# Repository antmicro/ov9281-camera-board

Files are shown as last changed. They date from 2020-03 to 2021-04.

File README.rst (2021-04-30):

========================
OV9281 Dual camera board
========================

Copyright (c) 2019-2021 `Antmicro <https://www.antmicro.com>`_

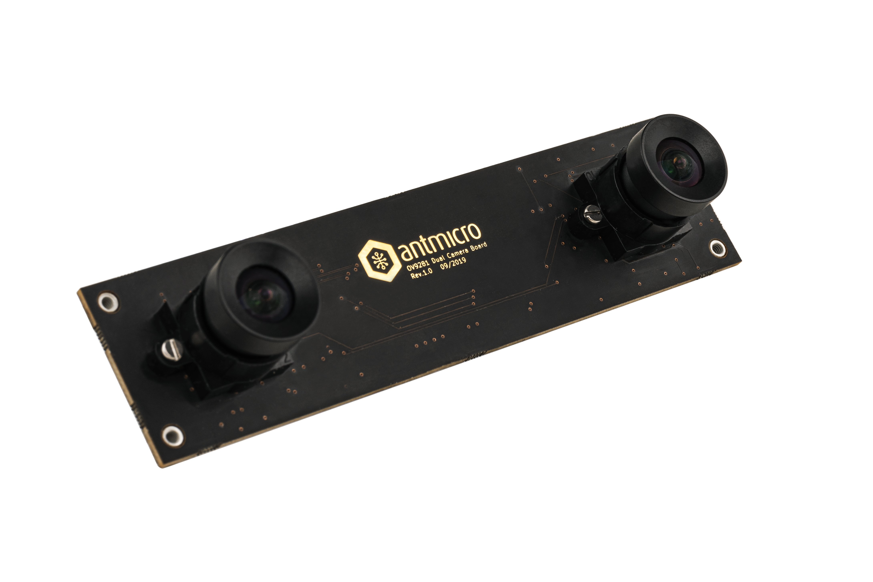
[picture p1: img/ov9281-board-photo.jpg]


Overview
========

This repository contains open hardware design files for a dual camera module created by `Antmicro <https://antmicro.com/>`_.
This board is equipped with a pair of 1-megapixel `OmniVision OV9281 <https://www.ovt.com/sensors/OV9281>`_ image sensors with mounting holes for standard S-Mount (M12) lens holders.
Each sensor can be connected to a host platform via a separate 2-lane MIPI CSI-2 interface.
The PCB design files have been written in KiCad and released as Open Source Hardware (OSHW).

Key Features
============

+------------------------------+--------------------------------------+
| Image sensor(s):             | 2 x monochrome global shutter OV9281 |
+------------------------------+--------------------------------------+
| Pixel size:                  | 3μm x 3 μm                           |
+------------------------------+--------------------------------------+
| Active array size:           | 1280 x 800                           |
+------------------------------+--------------------------------------+
| Optical size:                | 1/4 inch                             |
+------------------------------+--------------------------------------+
| Lens mount:                  | M-12 (S-Mount)                       |
+------------------------------+--------------------------------------+
| Output interface:            | 50-pin FFC connector                 |
+------------------------------+--------------------------------------+
| Output formats:              | 8/10-bit BW RAW                      |
+------------------------------+--------------------------------------+
| Maximum image transfer rate: | 1280 x 800 @60 fps                   |
+------------------------------+--------------------------------------+

Interface connector
===================

The board uses a 50-pin FFC connector which exposes two separate MIPI CSI interfaces for both cameras, along with power supply rails and separate I2C buses used for sensor configuration.
The board is electrically compatible with Antmicro's products and open hardware designs, including `Jetson Nano baseboard <https://github.com/antmicro/jetson-nano-baseboard>`_,
`Google Coral Baseboard <https://github.com/antmicro/google-coral-baseboard>`_ or `Zynq Video Board <https://github.com/antmicro/zynq-video-board>`_.

For more details regarding the on-board circuitry please refer to the respective schematic sheets.

Mechanics
=========

Board dimensions:

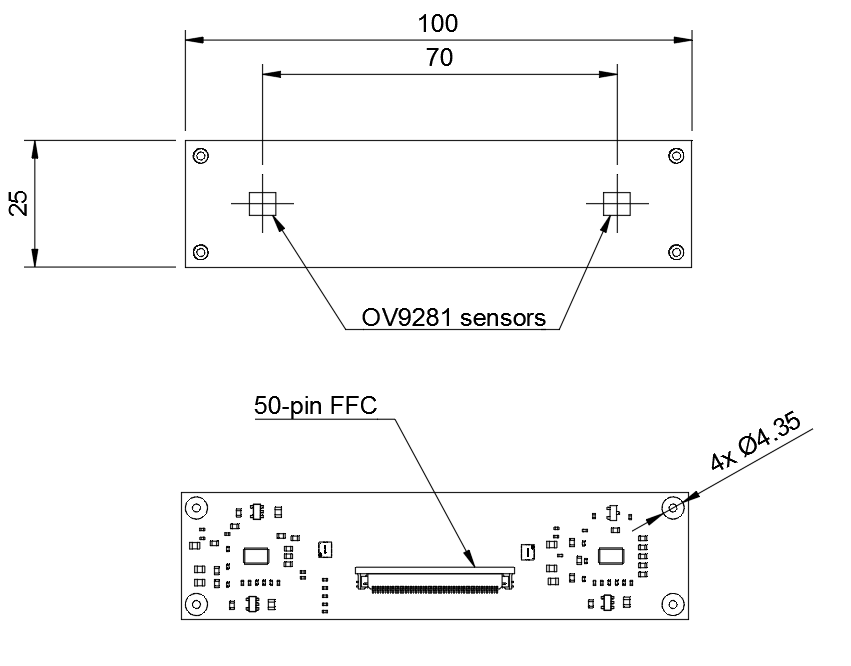
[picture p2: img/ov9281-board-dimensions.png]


License
=======

`Apache-2.0 <LICENSE>`_

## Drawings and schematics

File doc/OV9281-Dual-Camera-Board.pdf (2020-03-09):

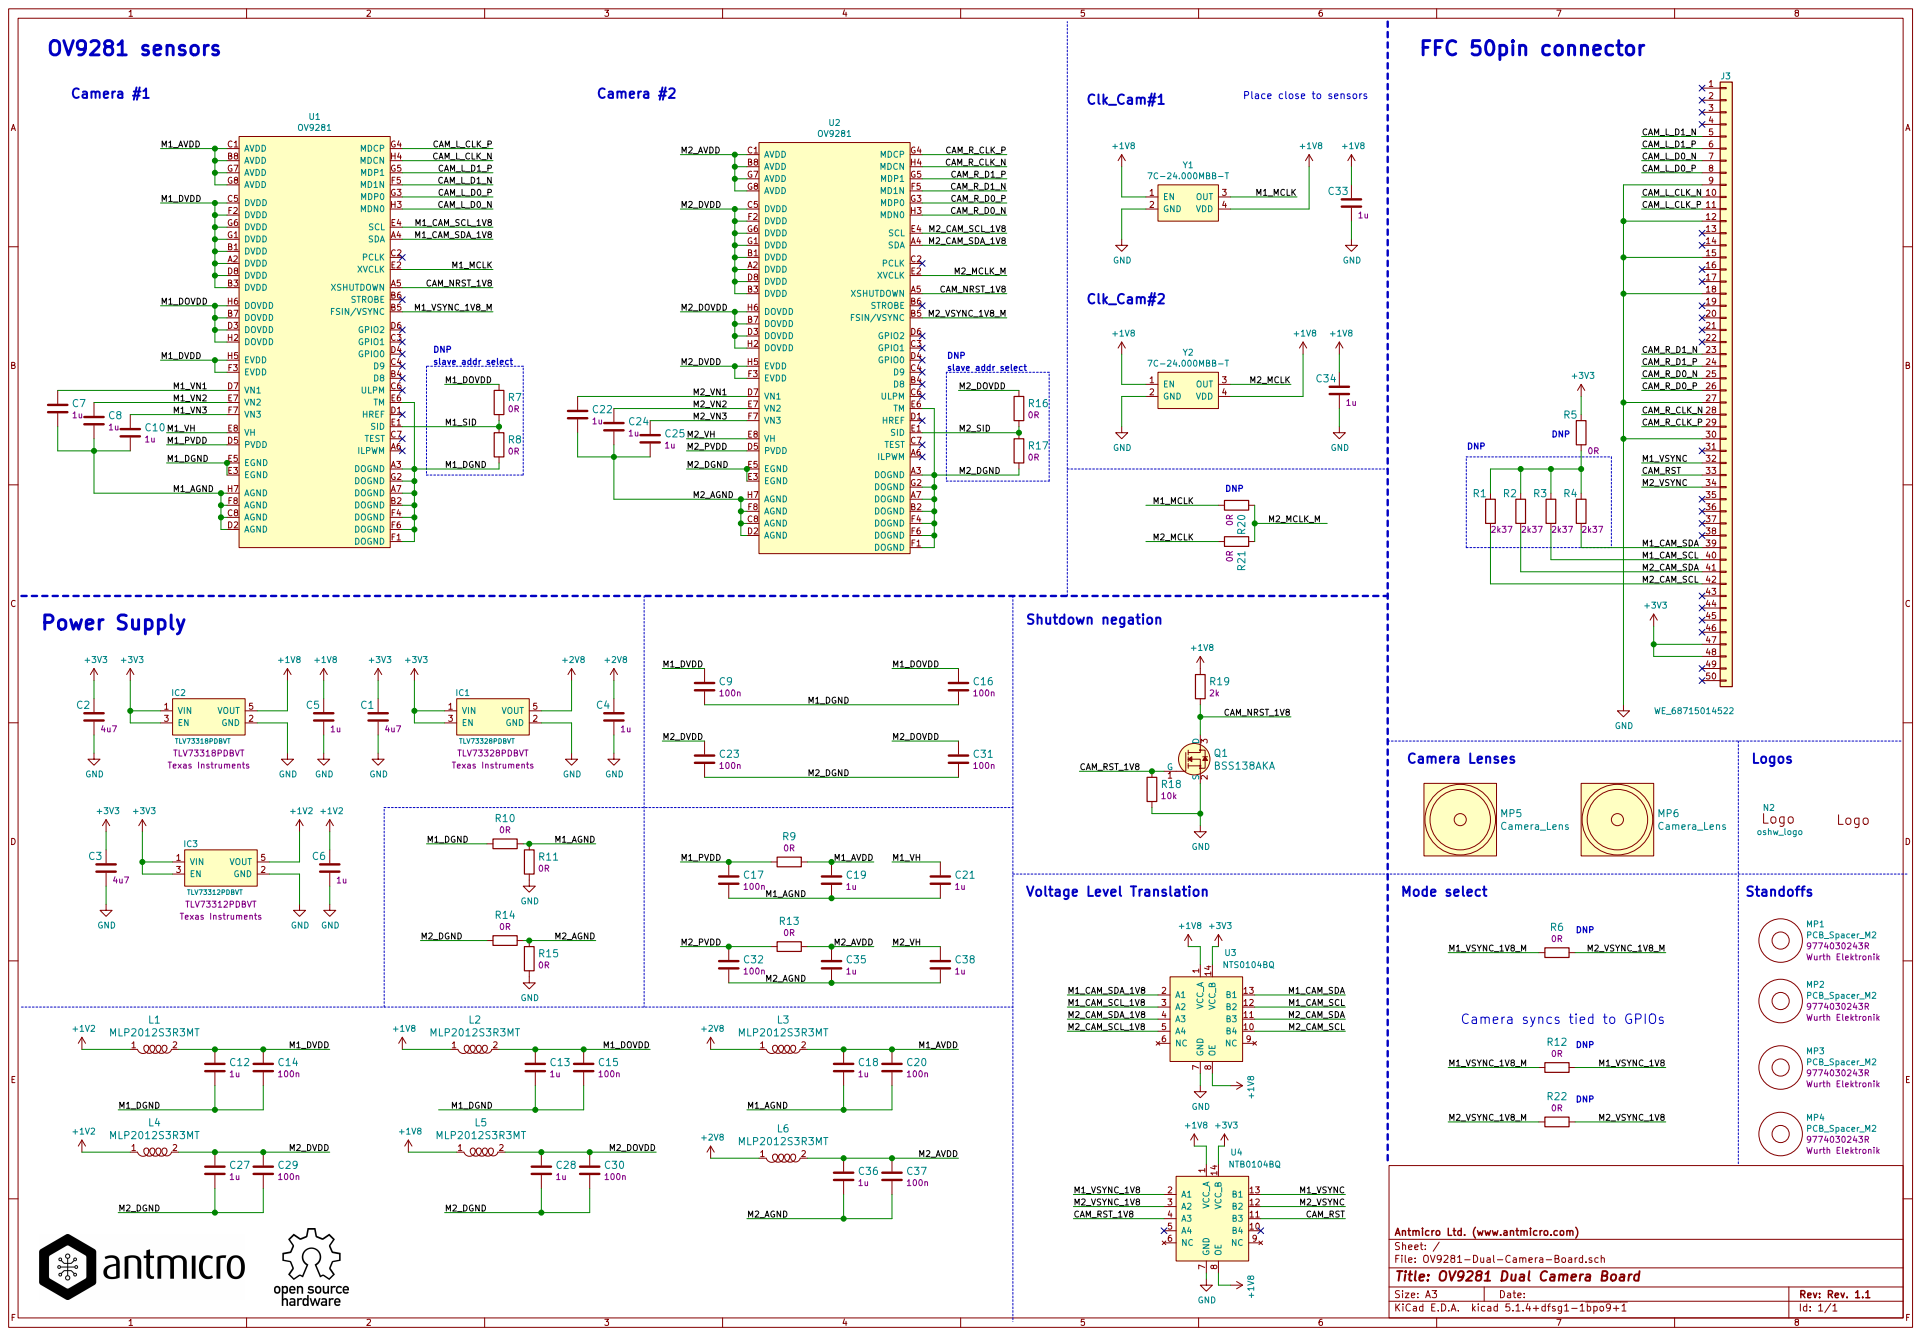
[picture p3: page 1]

File: OV9281-Dual-Camera-Board.sch Sheet: / Antmicro Ltd. (www.antmicro.com) R9

Camera syncs tied to GPIOs

Id: 1/1 Title: OV9281 Dual Camera Board

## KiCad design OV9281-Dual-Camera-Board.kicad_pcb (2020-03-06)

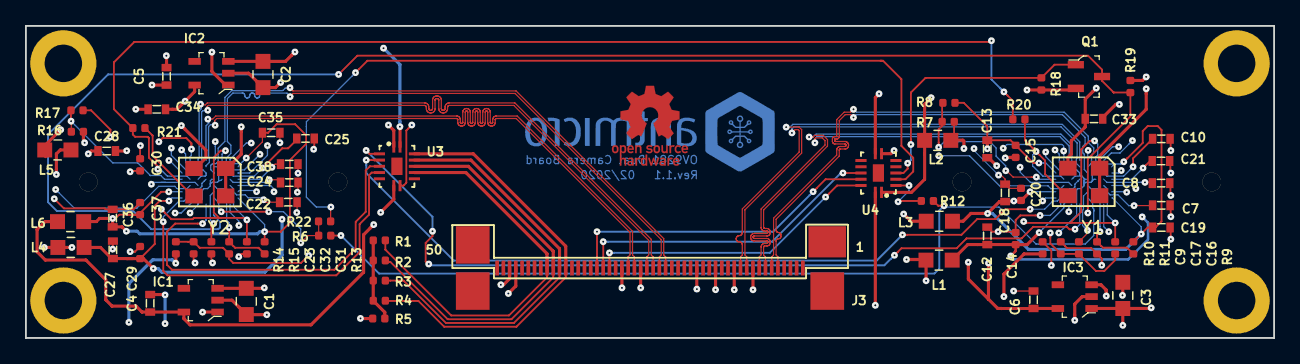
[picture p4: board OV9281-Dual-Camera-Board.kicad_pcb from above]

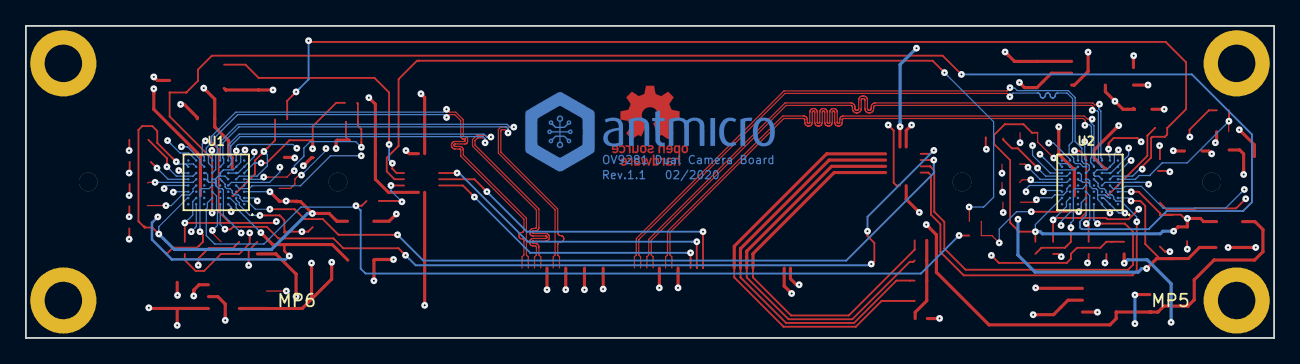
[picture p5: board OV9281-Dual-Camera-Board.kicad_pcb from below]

Board: 4 copper layers, 100.0 x 25.0 mm, 83 parts (5 on the bottom side), 60 nets.

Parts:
C1, C2, C3: C_4u7_0805; 0805-cap
C4, C5, C6, C7, C8, C10, C12, C13, C18, C19, C21, C22, C24, C25, C27, C28, C33, C34, C35, C36, C38: C_1u_0603; 0603-cap
C9, C14, C15, C16, C17, C20, C23, C29, C30, C31, C32, C37: C_100n_0402_6V3; 0402-cap
IC1: TLV73328PDBVT; SOT-23-5
IC2: TLV73318PDBVT; SOT-23-5
IC3: TLV73312PDBVT; SOT-23-5
J3: WE_68715014522
L1, L2, L3, L4, L5, L6: MLP2012S3R3MT; 0805-res
MP1, MP2, MP3, MP4: PCB_Spacer_M2; 9774030243R
MP5, MP6: Camera_Lens; Camera_Lens_20mm
N1: antmicro_logo; antmicro-logo_scaled_20mm
N2: oshw_logo; oshw-logo
Q1: BSS138AKA; SOT-23-3
R1, R2, R3, R4: R_2k37_0402; 0402-res
R5, R6, R7, R8, R9, R10, R11, R12, R13, R14, R15, R16, R17, R20, R21, R22: R_0R_0402; 0402-res
R18: R_10k_0402; 0402-res
R19: R_2k_0402; 0402-res
U1, U2: OV9281; ov9281
U3: NTS0104BQ; QDHVQFN14
U4: NTB0104BQ; QDHVQFN14
Y1, Y2: Farnell_1842027; 7C-24.000MBB-T

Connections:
+1V2: C6.1, IC3.5, L1.1, L4.1
+1V8: C5.1, C33.1, C34.1, IC2.5, L2.1, L5.1, R19.1, U3.1, U3.8, U4.1, U4.8, Y1.1, Y1.4, Y2.1, Y2.4
+2V8: C4.1, IC1.5, L3.1, L6.1
+3V3: C1.1, C2.1, C3.1, IC1.1, IC1.3, IC2.1, IC2.3, IC3.1, IC3.3, J3.47, J3.48, R5.1, U3.14, U4.14
/CAM_L_CLK_N: J3.10, U1.H4
/CAM_L_CLK_P: J3.11, U1.G4
/CAM_L_D0_N: J3.7, U1.H3
/CAM_L_D0_P: J3.8, U1.G3
/CAM_L_D1_N: J3.5, U1.F5
/CAM_L_D1_P: J3.6, U1.G5
/CAM_NRST_1V8: Q1.3, R19.2, U1.A5, U2.A5
/CAM_RST: J3.33, U4.11
/CAM_RST_1V8: Q1.1, R18.1, U4.4
/CAM_R_CLK_N: J3.28, U2.H4
/CAM_R_CLK_P: J3.29, U2.G4
/CAM_R_D0_N: J3.25, U2.H3
/CAM_R_D0_P: J3.26, U2.G3
/CAM_R_D1_N: J3.23, U2.F5
/CAM_R_D1_P: J3.24, U2.G5
/M1_AGND: C7.2, C8.2, C10.2, C17.2, C18.2, C19.2, C20.2, C21.2, R10.2, R11.1, U1.C8, U1.D2, U1.F8, U1.H7
/M1_AVDD: C18.1, C19.1, C20.1, L3.2, R9.2, U1.B8, U1.C1, U1.G7, U1.G8
/M1_CAM_SCL: J3.40, R3.2, U3.12
/M1_CAM_SCL_1V8: U1.E4, U3.3
/M1_CAM_SDA: J3.39, R4.2, U3.13
/M1_CAM_SDA_1V8: U1.A4, U3.2
/M1_DGND: C9.2, C12.2, C13.2, C14.2, C15.2, C16.2, R8.2, R10.1, U1.A3, U1.A7, U1.B2, U1.E3, U1.E5, U1.E6, U1.F1, U1.F4, U1.F6, U1.G2
/M1_DOVDD: C13.1, C15.1, C16.1, L2.2, R7.1, U1.B7, U1.D3, U1.H2, U1.H6
/M1_DVDD: C9.1, C12.1, C14.1, L1.2, U1.A2, U1.B1, U1.B3, U1.C5, U1.D8, U1.F2, U1.F3, U1.G1, U1.G6, U1.H5
/M1_MCLK: R20.2, U1.E2, Y1.3
/M1_PVDD: C17.1, R9.1, U1.D5
/M1_SID: R7.2, R8.1, U1.E1
/M1_VH: C21.1, U1.E8
/M1_VN1: C7.1, U1.D7
/M1_VN2: C8.1, U1.E7
/M1_VN3: C10.1, U1.F7
/M1_VSYNC: J3.32, U4.13
/M1_VSYNC_1V8: R12.2, U4.2
/M1_VSYNC_1V8_M: R6.1, R12.1, U1.B5
/M2_AGND: C22.2, C24.2, C25.2, C32.2, C35.2, C36.2, C37.2, C38.2, R14.2, R15.1, U2.C8, U2.D2, U2.F8, U2.H7
/M2_AVDD: C35.1, C36.1, C37.1, L6.2, R13.2, U2.B8, U2.C1, U2.G7, U2.G8
/M2_CAM_SCL: J3.42, R1.2, U3.10
/M2_CAM_SCL_1V8: U2.E4, U3.5
/M2_CAM_SDA: J3.41, R2.2, U3.11
/M2_CAM_SDA_1V8: U2.A4, U3.4
/M2_DGND: C23.2, C27.2, C28.2, C29.2, C30.2, C31.2, R14.1, R17.2, U2.A3, U2.A7, U2.B2, U2.E3, U2.E5, U2.E6, U2.F1, U2.F4, U2.F6, U2.G2
/M2_DOVDD: C28.1, C30.1, C31.1, L5.2, R16.1, U2.B7, U2.D3, U2.H2, U2.H6
/M2_DVDD: C23.1, C27.1, C29.1, L4.2, U2.A2, U2.B1, U2.B3, U2.C5, U2.D8, U2.F2, U2.F3, U2.G1, U2.G6, U2.H5
/M2_MCLK: R21.2, Y2.3
/M2_MCLK_M: R20.1, R21.1, U2.E2
/M2_PVDD: C32.1, R13.1, U2.D5
/M2_SID: R16.2, R17.1, U2.E1
/M2_VH: C38.1, U2.E8
/M2_VN1: C22.1, U2.D7
/M2_VN2: C24.1, U2.E7
/M2_VN3: C25.1, U2.F7
/M2_VSYNC: J3.34, U4.12
/M2_VSYNC_1V8: R22.2, U4.3
/M2_VSYNC_1V8_M: R6.2, R22.1, U2.B5
GND: C1.2, C2.2, C3.2, C4.2, C5.2, C6.2, C33.2, C34.2, IC1.2, IC2.2, IC3.2, J3.9, J3.12, J3.15, J3.18, J3.27, J3.30, Q1.2, R11.2, R15.2, R18.2, U3.7, U4.7, Y1.2, Y2.2
unnamed: R1.1, R2.1, R3.1, R4.1, R5.2

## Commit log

2020-03-06 Unified power rails, added power supply filters
    [OV9281.sch]
2020-03-06 Added voltage level translation
    [OV9281.sch]
2020-03-06 Updated transistor and inductors from libraries
    [OV9281.sch]
2020-03-06 Edited design rules to make bigger clearance
    [OV9281-B.Cu.gbr, OV9281-B.Fab.gbr, OV9281-B.Mask.gbr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]
2020-03-06 Defined initial component placement
    [OV9281.kicad_pcb, _saved_OV9281.sch]
2020-03-06 PCB routing
    [OV9281-B.Cu.gbr, OV9281-B.Fab.gbr, OV9281-B.Mask.gbr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]
2020-03-06 PCB ready for manufacturing
    [OV9281-B.Cu.gbr, OV9281-B.Fab.gbr, OV9281-B.Mask.gbr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]
2020-03-06 Added mounting holes for lenses
    [OV9281-B.Cu.gbr, OV9281-B.Fab.gbr, OV9281-B.Mask.gbr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]
2020-03-06 Started rev.1.1, added resistors for choosing VSYNC connection
    [OV9281-B.Adhes.gbr, OV9281-B.CrtYd.gbr, OV9281-B.Cu.gbr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]
2020-03-06 Moved some low speed signal tracks
    [OV9281-B.Fab.gbr, OV9281-Dual-Camera-Board-Rev.1.1-B.Adhes.gbr, OV9281-Dual-Camera-Board-Rev.1.1-B.CrtYd.gbr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]
2020-03-06 Minor changes
    [OV9281-Dual-Camera-Board-Rev.1.1.kicad_pcb]
2020-03-06 Pick and Place merged into a single file
    [OV9281-Dual-Camera-Board-Rev.1.1-pnp-bottom.csv, OV9281-Dual-Camera-Board-Rev.1.1-pnp.csv]
2020-03-06 Updated file structure
    [OV9281-B.Cu.gbr, OV9281-B.Fab.gbr, OV9281-B.Mask.gbr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]
2020-03-06 Unified file names and references
    [OV9281-Dual-Camera-Board-B_Adhes.gbr, OV9281-Dual-Camera-Board-B_CrtYd.gbr, OV9281-Dual-Camera-Board-B_Cu.gbr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]
2020-03-06 Added OSHW logo, updated hole spacing for lens mount
    [OV9281-Dual-Camera-Board.kicad_pcb, OV9281-Dual-Camera-Board.sch]
2020-03-06 Minor fix
    [OV9281-Dual-Camera-Board.kicad_pcb]
2020-03-06 Updated project structure
    [OV9281-Dual-Camera-Board-B_Adhes.gbr, OV9281-Dual-Camera-Board-B_CrtYd.gbr, OV9281-Dual-Camera-Board-B_Cu.gbr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]
2020-03-06 Updated virtual components on PCB
    [OV9281-Dual-Camera-Board.kicad_pcb]
2020-03-09 Fixed logotypes, exported new schematics PDF
    [OV9281-Dual-Camera-Board.sch]
2021-03-09 Bump revision to 1.1.0
    [OV9281-Dual-Camera-Board.sch]
